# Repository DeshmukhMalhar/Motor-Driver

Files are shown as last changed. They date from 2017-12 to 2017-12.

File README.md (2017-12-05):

__Motor Driver__

This Board receives a pulse like input, similat to a Servo.
The input range is from 0 degrees to 90 degrees for one direction
and 90 to 180 degrees for other direction 
The Board is still under devlopement.
It will be optimised for single sided PCB as to simplify etching and testing at home

A full closed loop RPM control system will be devloped for this

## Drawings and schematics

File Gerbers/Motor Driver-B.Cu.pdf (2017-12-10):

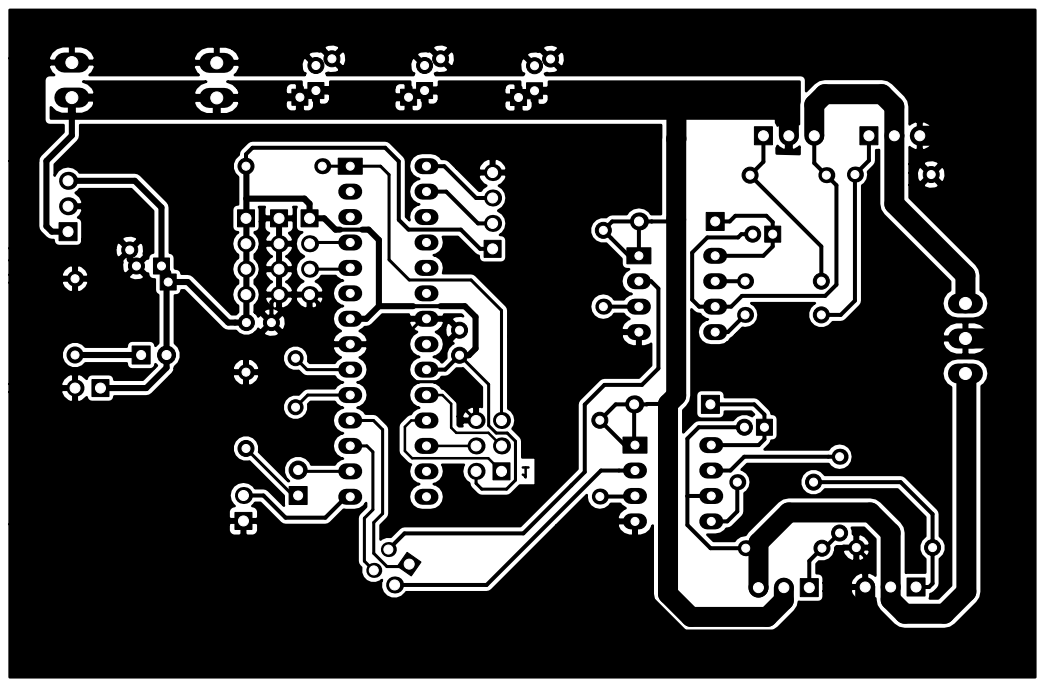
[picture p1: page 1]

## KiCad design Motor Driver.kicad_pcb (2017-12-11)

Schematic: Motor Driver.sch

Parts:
C1: 0.1; C_Disc_D3.0mm_W2.0mm_P2.50mm
C3: 10u; CP_Radial_D10.0mm_P2.50mm_P5.00mm
C5: 0.1C; C_Disc_D3.0mm_W2.0mm_P2.50mm
C7: 47u; CP_Radial_D10.0mm_P2.50mm_P5.00mm
C9, C10: CP_Small; CP_Radial_D5.0mm_P2.00mm
C11, C12: CP_Small; CP_Radial_D10.0mm_P2.50mm_P5.00mm
CON1: AVR-ISP-6; Pin_Header_Straight_2x03_Pitch2.54mm
D1, D2: D; D_A-405_P7.62mm_Horizontal
D3, D4: LED_ALT; LED_D5.0mm
J1, J2, J11: Conn_01x02; Pin_Header_Straight_1x02_Pitch2.54mm
J3, J4, J5, J10: Conn_01x04; Pin_Header_Straight_1x04_Pitch2.54mm
J6: Conn_02x02_Odd_Even; Pin_Header_Straight_2x02_Pitch2.54mm
J7, J8: Conn_01x02; WAGO_734_2pin_Straight_RuggedPads
J9: Conn_01x03; WAGO_734_3pin_Straight_RuggedPads
Q1, Q2, Q3, Q4: IRF3205; TO-220-3_Vertical
R1: 10K; R_Axial_DIN0207_L6.3mm_D2.5mm_P7.62mm_Horizontal
R2, R9: 510; R_Axial_DIN0207_L6.3mm_D2.5mm_P7.62mm_Horizontal
R3, R4, R5, R6, R7, R8, R10, R11, R12, R13: R; R_Axial_DIN0207_L6.3mm_D2.5mm_P7.62mm_Horizontal
R14, R15, R16: 200; R_Axial_DIN0207_L6.3mm_D2.5mm_P7.62mm_Horizontal
U1: L7805; TO-220-3_Vertical
U2: PC817; DIP-4_W7.62mm
U3: ATMEGA328P-PU; DIP-28_W7.62mm_Socket_LongPads
U5, U6: IR2104; DIP-8_W7.62mm_Socket_LongPads
Y2: Crystal; Crystal_HC18-U_Vertical

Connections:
+5V: C1.1, C5.1, C7.1, CON1.2, D3.2 (A), J2.1, J4.1, J4.2, J4.3, J4.4, J5.1, J10.1, R1.1, R16.2, U1.3 (OUT), U3.7 (VCC), U3.20 (AVCC)
/IN1: J6.1, U3.11 ((PCINT21/OC0B/T1)PD5)
/IN2: J6.4, U3.12 ((PCINT22/OC0A/AIN0)PD6)
/INPUT_L: J1.2, R15.2, U2.3, U3.14 ((PCINT0/CLKO/ICP1)PB0)
/RST: CON1.5, R1.2, U3.1 ((PCINT14/~RESET~)PC6)
GND: C1.2, C3.2, C5.2, C7.2, C11.2, C12.2, CON1.6, J1.1, J2.2, J3.1, J3.2, J3.3, J3.4, J5.4, J7.2, J8.2, J9.2, J10.4, Q2.3 (S), Q4.3 (S), R2.2, R9.2, R10.1, R11.2, R15.1, U1.2 (GND), U3.8 (GND), U3.22 (GND), U5.4, U6.4
unnamed: C9.1, D1.1 (K), U5.8
unnamed: C9.2, J9.1, Q1.3 (S), Q2.2 (D), R12.2, U5.6
unnamed: C10.1, D2.1 (K), U6.8
unnamed: C10.2, J9.3, Q3.3 (S), Q4.2 (D), R13.2, U6.6
unnamed: CON1.1, U3.18 ((PCINT4/MISO)PB4)
unnamed: CON1.3, U3.19 ((PCINT5/SCK)PB5)
unnamed: CON1.4, U3.17 ((PCINT3/OC2A/MOSI)PB3)
unnamed: D3.1 (K), R9.1
unnamed: D4.1 (K), R2.1
unnamed: D4.2 (A), U3.13 ((PCINT23/AIN1)PD7)
unnamed: J5.2, U3.4 ((PCINT18/INT0)PD2)
unnamed: J5.3, U3.5 ((PCINT19/OC2B/INT1)PD3)
unnamed: J6.2, U6.2
unnamed: J6.3, U5.2
unnamed: J10.2, U3.27 ((PCINT12/SDA/ADC4)PC4)
unnamed: J10.3, U3.28 ((PCINT13/SCL/ADC5)PC5)
unnamed: J11.1, U2.2
unnamed: J11.2, R14.2
unnamed: Q1.1 (G), R5.1, R12.1
unnamed: Q2.1 (G), R6.1, R10.2
unnamed: Q3.1 (G), R7.1, R13.1
unnamed: Q4.1 (G), R8.1, R11.1
unnamed: R3.2, U5.3
unnamed: R4.2, U6.3
unnamed: R5.2, U5.7
unnamed: R6.2, U5.5
unnamed: R7.2, U6.7
unnamed: R8.2, U6.5
unnamed: R14.1, U2.1
unnamed: R16.1, U2.4
unnamed: U3.9 ((PCINT6/XTAL1/TOSC1)PB6), Y2.1
unnamed: U3.10 ((PCINT7/XTAL2/TOSC2)PB7), Y2.2
VCC: C3.1, C11.1, C12.1, D1.2 (A), D2.2 (A), J7.1, J8.1, Q1.2 (D), Q3.2 (D), R3.1, R4.1, U1.1 (IN), U5.1, U6.1

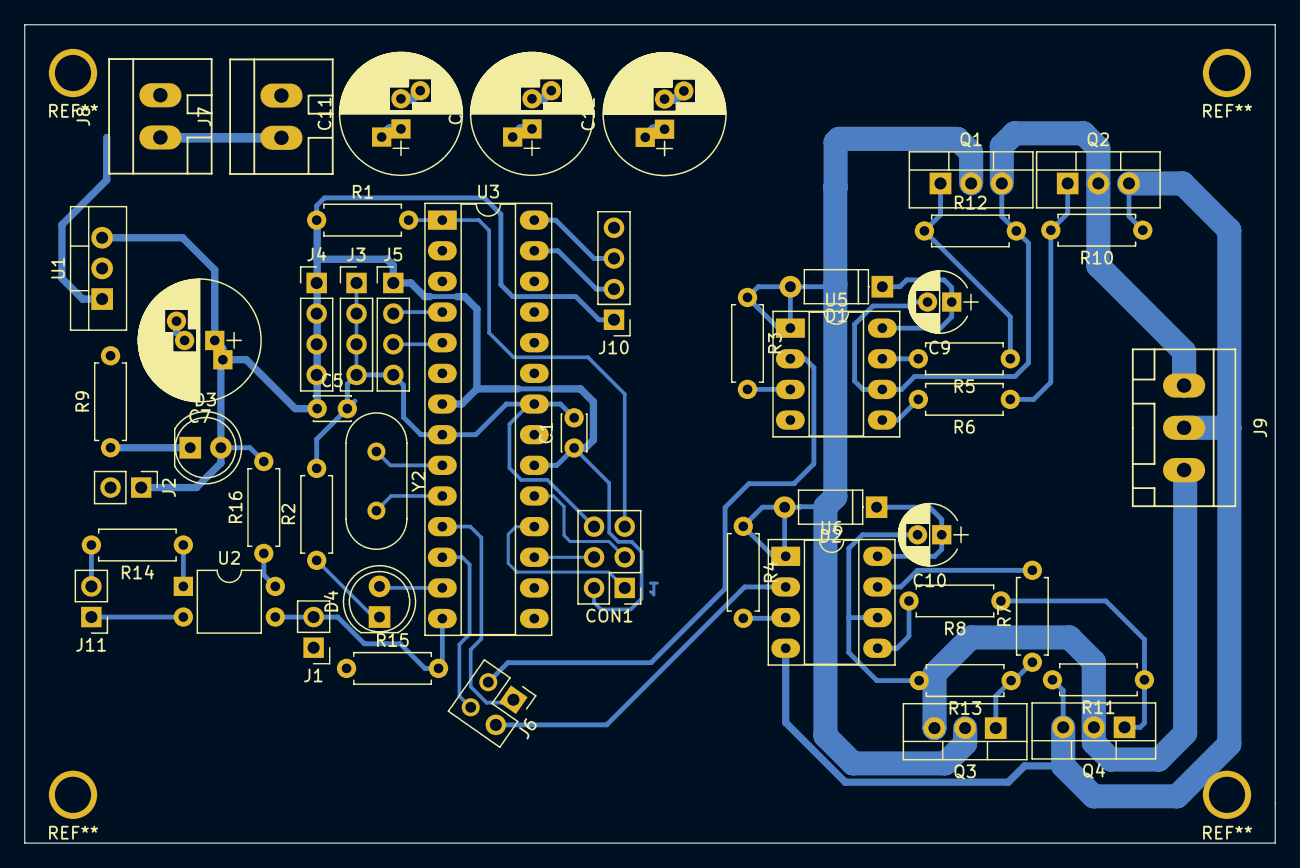
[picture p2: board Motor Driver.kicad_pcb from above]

Board: 2 copper layers, 103.6 x 67.8 mm, 50 parts (0 on the bottom side), 39 nets.

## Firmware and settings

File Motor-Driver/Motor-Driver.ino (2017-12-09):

/*
   http://github.com/DeshmukhMalhar/Motor-Driver
   Device : ATMega328P

*/volatile uint16_t old, newT, ticks;
volatile uint8_t count = 0;
ISR(TIMER1_CAPT_vect) {
<<<<<<< HEAD
  if (digitalRead(8) == HIGH) {
    newT = ICR1;
    TCCR1B = 0b00000011;
  } else {
    old = ICR1;
    TCCR1B = 0b01000011;
=======

  if (digitalRead(8)==HIGH) {
    ticks1 = ICR1;
    TCCR1B |= (0 << ICES1);
    subb = 1;
  } else {
    ticks2 = ICR1;
    TCCR1B |= (1 << ICES1);
    subb = 0;
>>>>>>> 231771da58c64ddfd68c5e21636383e907a38638
  }

}
ISR (TIMER1_OVF_vect) {
  
    digitalWrite(7, !digitalRead(7));
  
}
void setup() {
<<<<<<< HEAD

  DDRD = 0b11100000;
  DDRB = 0x00;

  //Timer1 setup for ICP, one count is approx 4 ms ~ (3.814697266ms)
=======
  //pinmodes
  pinMode(8, INPUT);
  pinMode(5, OUTPUT);
  pinMode(6, OUTPUT);
  
  //Timer1 setup
>>>>>>> 231771da58c64ddfd68c5e21636383e907a38638
  TCCR1A = 0b00000000;
  TCCR1B = 0b01000011;
  TCCR1C = 0b00000000;
  TIMSK1 = 0b00100001;

  //Timer0 setup as Phase correct PWM
  TCCR0A = 0b10100001;
  TCCR0B = 0b00000010;
  TIMSK0 = 0b00000000;//all 3 of OCR0A , OCR0B and TMR0_OVF interrupts are on
  TCNT0 = 0;

}

void loop() {
<<<<<<< HEAD
  ticks = abs(old - newT);
  ticks = ticks - 136 ; //0 adjust

  if (ticks <= 0) {//136 is 544/4 ; 0 degrees is 544 us pulse ; one tick is 4ms ;180 degrees is 2400 ms ie 600 ticks,600-136 is 464 i.e max value.
    OCR0A = 0;
    OCR0B = 0;

  } else if (ticks > 0 && ticks <= 232) {
    OCR0A = ticks;
    OCR0B = 0;
  } else if (ticks > 232 && ticks <= 464) {
    OCR0A = 0;
    OCR0B = (ticks - 232);
=======
  ticks=ticks-136;
    if (ticks == 0) {
      OCR0A=0;
      OCR0B=0;
    } else if (ticks > 0 && ticks <= 232) {
      OCR0B = ticks;
      OCR0A = 0;
    } else if (ticks > 232 && ticks < 464) {
      OCR0A = ticks - 232;
      OCR0B = 0;
    }
>>>>>>> 231771da58c64ddfd68c5e21636383e907a38638
  }

}

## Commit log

2017-12-09 Minor Changes
    [Motor Driver.kicad_pcb]
2017-12-09 Updated SCH|PCB
    Updated the SCh for polarity change on the fly using the 2x2 pinheader
    PCB was completely newly designed
    [Motor Driver.kicad_pcb, Motor Driver.sch, _saved_Motor Driver.sch]
2017-12-09 Nightely Update
    [Motor Driver.kicad_pcb, Motor Driver.sch, _saved_Motor Driver.sch]
2017-12-10 Added Isolation
    Added an Optoisolator to isolate the input signal
    [Motor Driver.kicad_pcb, Motor Driver.sch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]
2017-12-11 updated 3D models
    [Motor Driver.kicad_pcb, Motor Driver.sch]
